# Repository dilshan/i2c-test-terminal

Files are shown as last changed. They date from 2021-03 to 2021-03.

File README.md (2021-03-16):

# I2C Master Mode Emulator

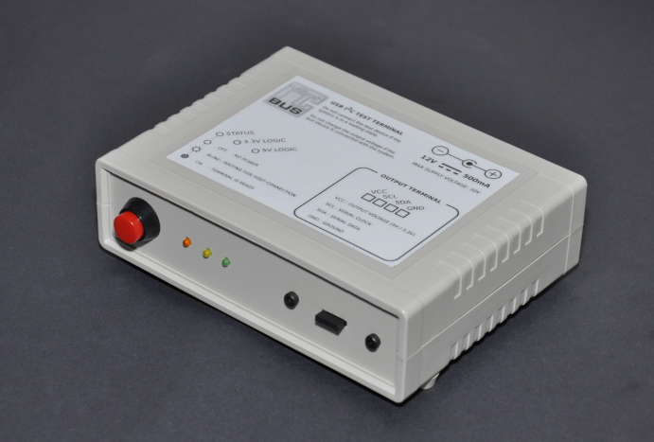
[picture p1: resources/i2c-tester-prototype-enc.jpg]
Prototype version of I2C master mode emulator


The I2C master mode emulator allows communication with I2C devices by sending or receiving data to/from the I2C bus. To issue the I2C commands, the emulator should connect to a PC over the USB port. After initializing the emulator, the PC and directly control the I2C slave chip/module.

This emulator is based on [ATmega16A](https://www.microchip.com/wwwproducts/en/ATmega16A) MCU. The USB communication channel is develop using the [V-USB](https://www.obdev.at/products/vusb/index.html) firmware.

To simplify the assembly, the PCB of this emulator is designed on a single-side board. The dimensions of the PCB are 96.77mm × 110.73mm. All the parts used in this project are through-hole-type, generally available components.

This emulator needs an external power supply, and the recommended supply voltage is between 12V - 15V.

The control software of the emulator is developed using libusb and tested only with *Linux* operating systems. The current firmware and control software support I2C emulation on 100kHz, 250kHz, and 400kHz clock rates.

Initially, we develop this emulator to work with 5V I2C devices, but later it has extended to work with 3.3V I2C devices. The 3.3V design is still under testing, and at the prototyping stage, we found a couple of issues in 3.3V mode.

In 3.3V mode, the required output level is available only if the emulator is in a "*ready*" state. In all the other states, it provides 5V output. **Therefore in 3.3V mode, necessary precautions need to be taken to protect the slave device from over-voltage damages.**

This project is an open-source hardware project. All the content of this project are distributed under the terms of the following license:

-   Hardware License: [CC BY 4.0](https://creativecommons.org/licenses/by/4.0/)
-   Software and firmware License: [MIT](https://github.com/dilshan/i2c-test-terminal/blob/main/LICENSE)
-   [Documentation](https://github.com/dilshan/i2c-test-terminal/wiki) License: [CC BY 4.0](https://creativecommons.org/licenses/by/4.0/)

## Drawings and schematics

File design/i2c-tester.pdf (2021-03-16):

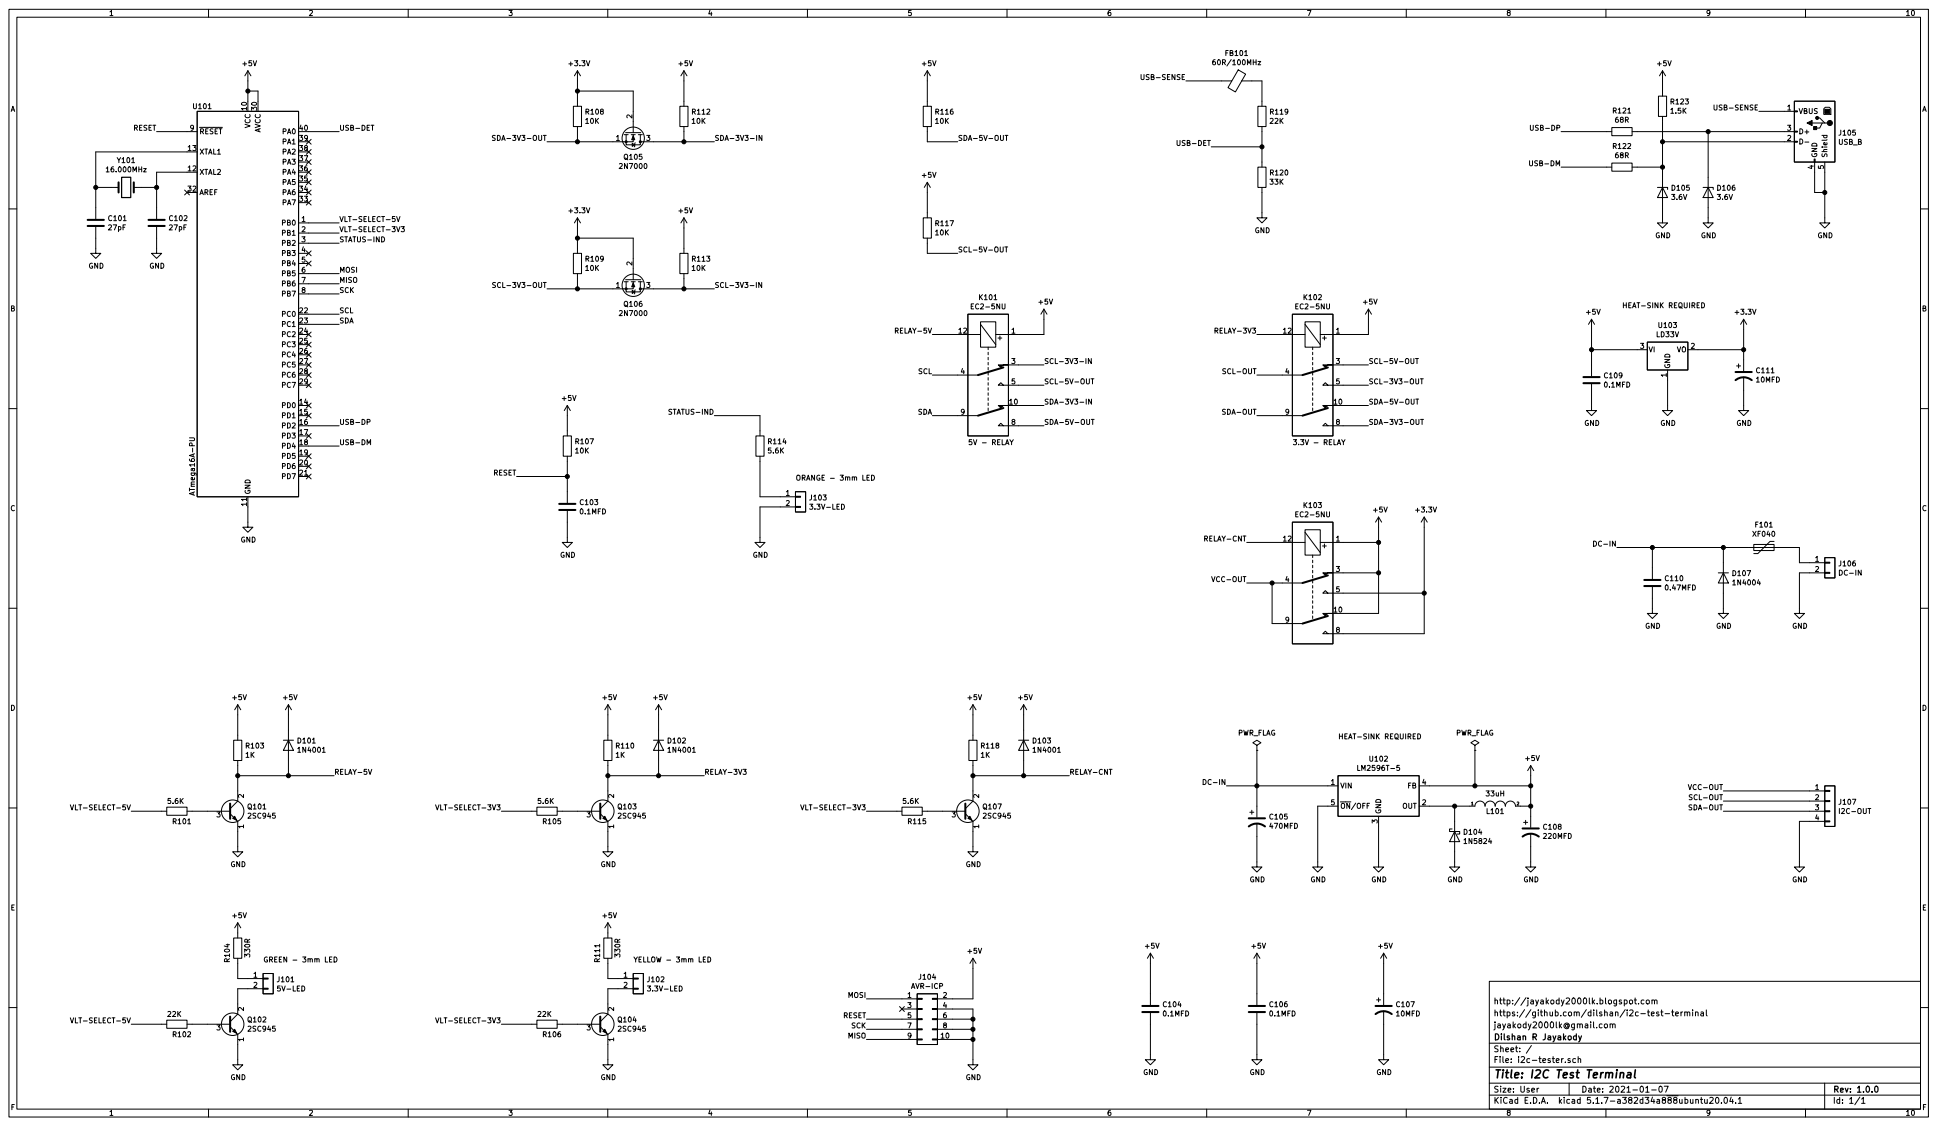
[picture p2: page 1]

SDA-3V3-OUT SCL-3V3-OUT USB-SENSEUSB-DET

2N7000 SDA USB-DET
SDA-3V3-OUT VLT-SELECT-5V

VCC-OUT SCL-3V3-IN

USB-DP USB-DM

http://jayakody2000lk.blogspot.com
https://github.com/dilshan/i2c-test-terminal
jayakody2000lk@gmail.com
Id: 1/1 Title: I2C Test Terminal File: i2c-tester.sch Sheet: / Dilshan R Jayakody

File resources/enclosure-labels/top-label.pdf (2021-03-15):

12V | 500mA

+ _

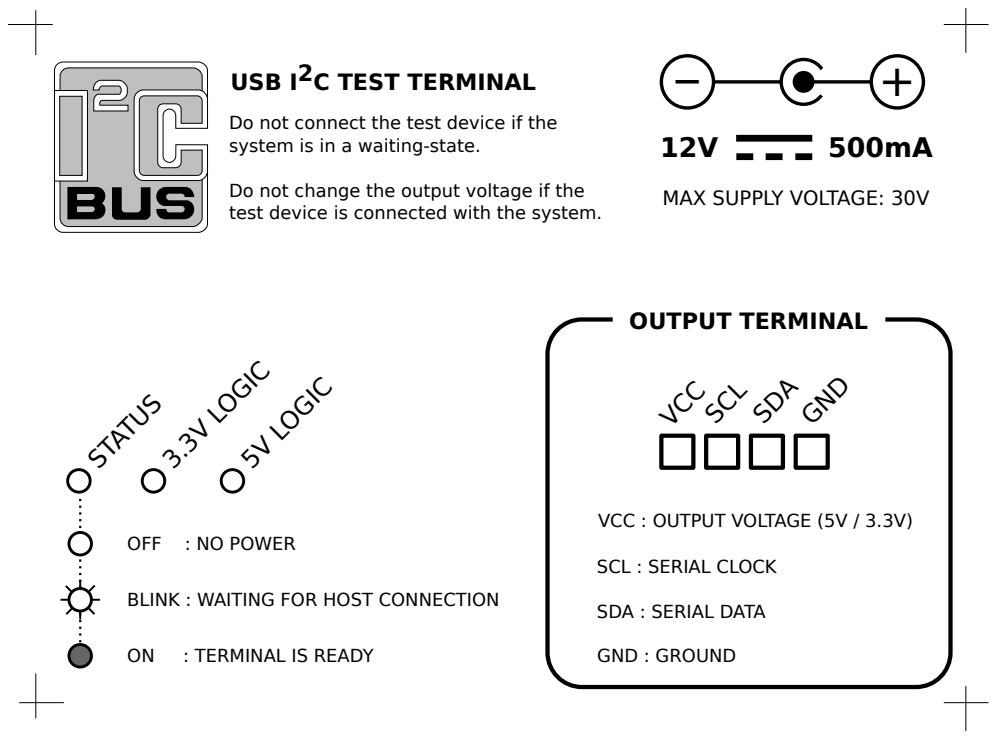
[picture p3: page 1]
STATUS; 3.3V LOGIC; : TERMINAL IS READY; 5V LOGIC; GND : GROUND; VCC; SCL; SDA; GND; OUTPUT TERMINAL

USB I2C TEST TERMINAL

Do not connect the test device if the
system is in a waiting-state.

Do not change the output voltage if the
test device is connected with the system.

MAX SUPPLY VOLTAGE: 30V

VCC : OUTPUT VOLTAGE (5V / 3.3V)

OFF : NO POWER

SCL : SERIAL CLOCK

BLINK : WAITING FOR HOST CONNECTION

SDA : SERIAL DATA

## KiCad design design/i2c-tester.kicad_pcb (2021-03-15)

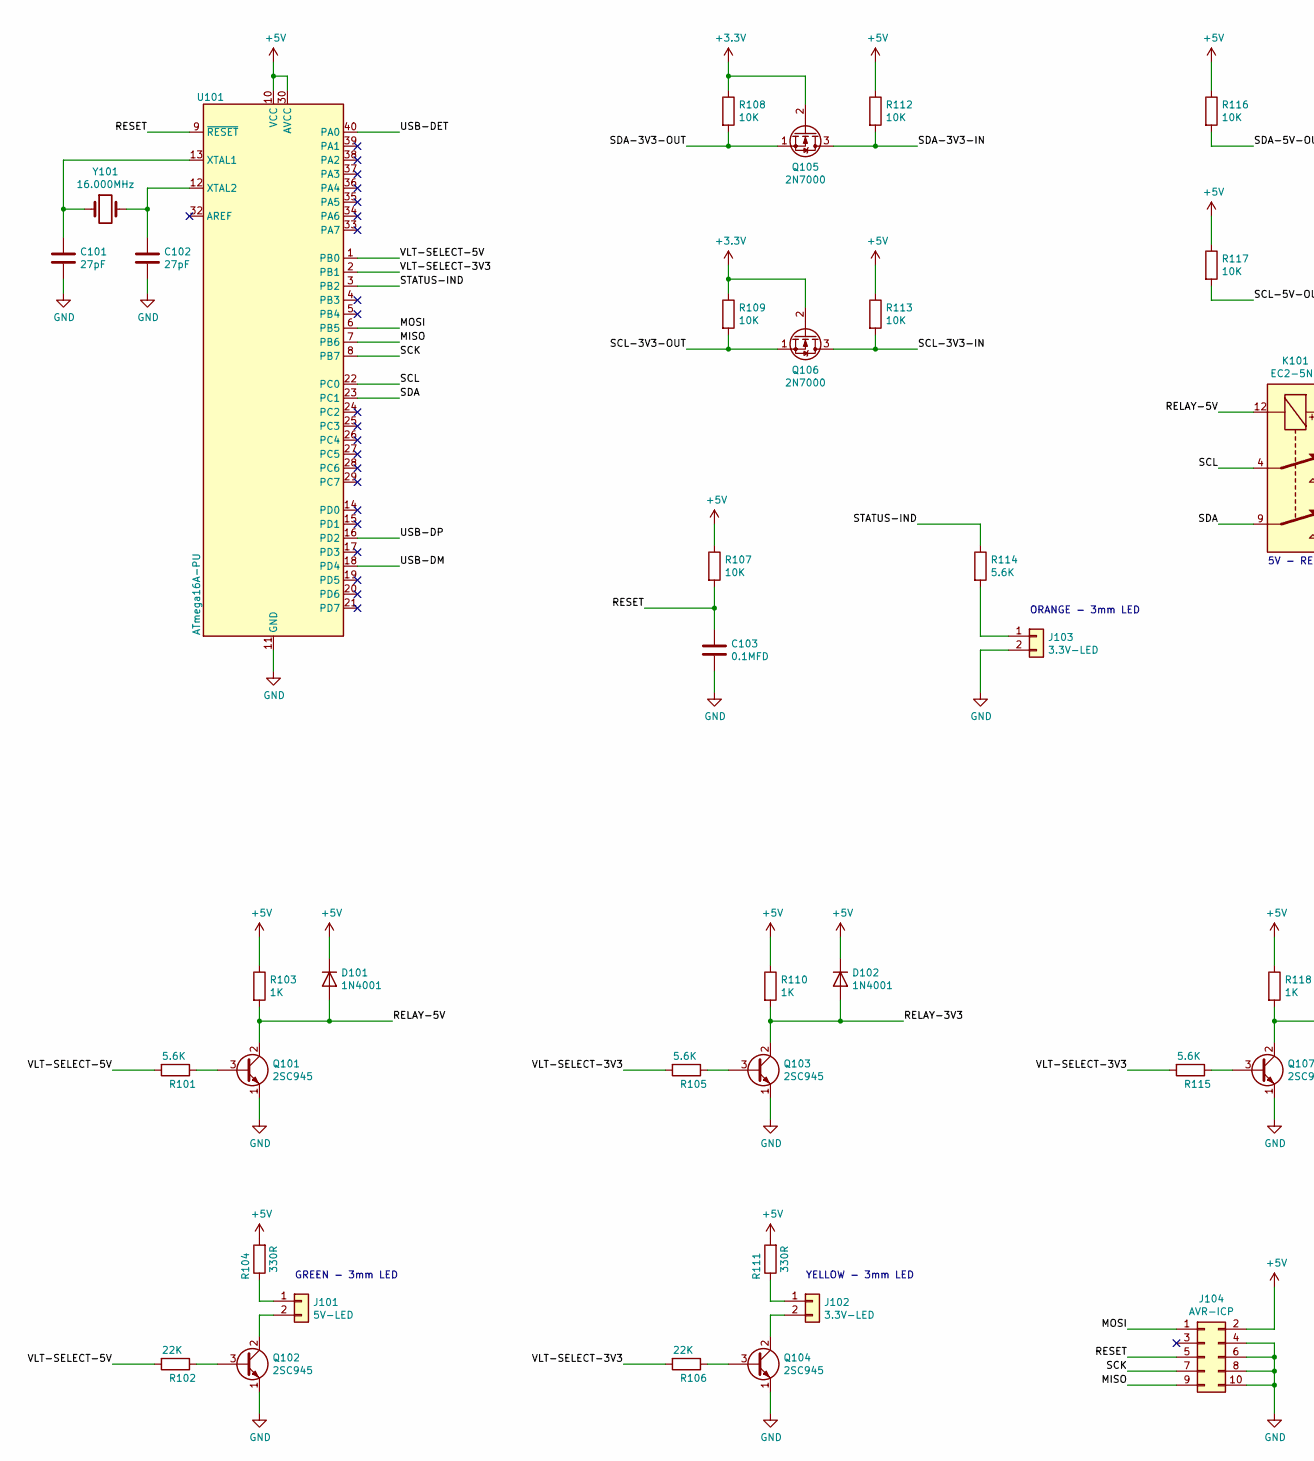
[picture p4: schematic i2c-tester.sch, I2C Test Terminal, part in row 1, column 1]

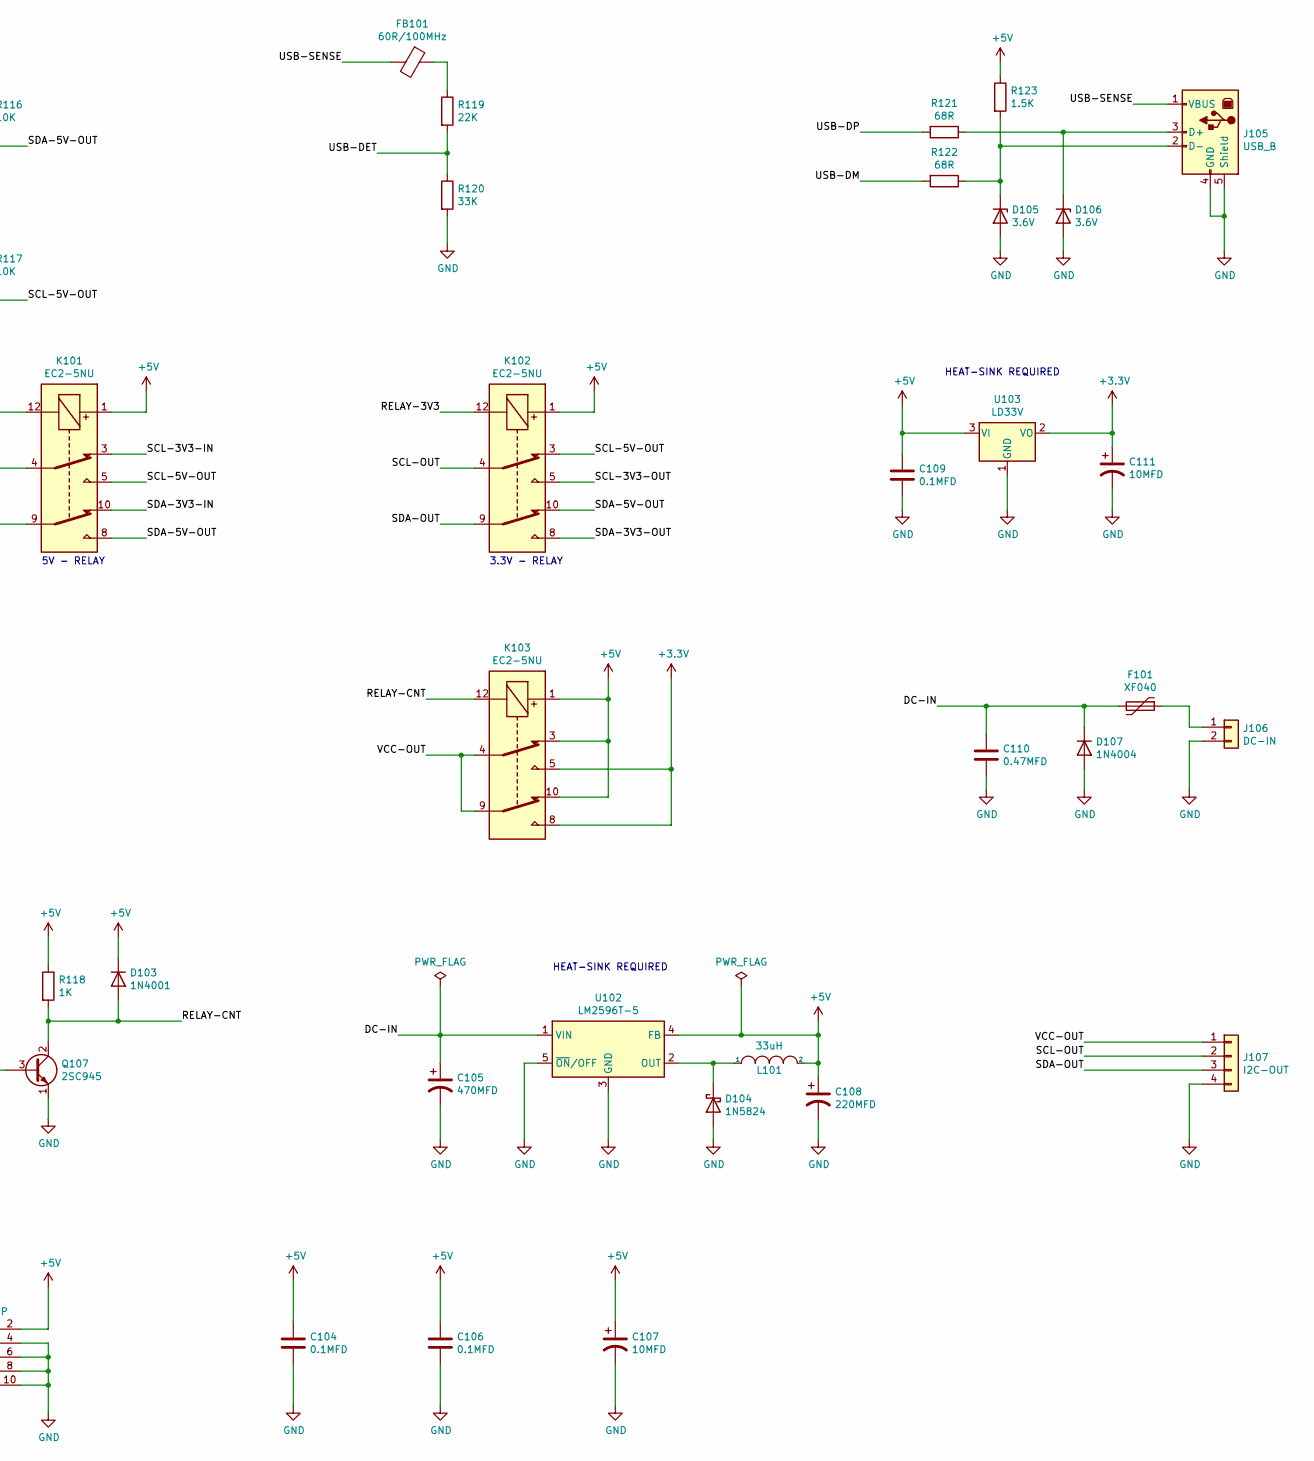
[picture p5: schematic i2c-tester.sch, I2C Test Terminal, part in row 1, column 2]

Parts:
C101, C102: 27pF; C_Disc_D5.0mm_W2.5mm_P2.50mm
C103, C104, C106, C109: 0.1MFD; C_Disc_D12.5mm_W5.0mm_P10.00mm
C105: 470MFD; CP_Radial_D8.0mm_P3.50mm
C107, C111: 10MFD; CP_Radial_D5.0mm_P2.00mm
C108: 220MFD; CP_Radial_D6.3mm_P2.50mm
C110: 0.47MFD; C_Rect_L16.5mm_W7.0mm_P15.00mm_MKT
D101, D102, D103: 1N4001; D_DO-41_SOD81_P10.16mm_Horizontal
D104: 1N5824; D_DO-41_SOD81_P10.16mm_Horizontal
D105, D106: 3.6V; D_DO-35_SOD27_P7.62mm_Horizontal
D107: 1N4004; D_DO-41_SOD81_P10.16mm_Horizontal
F101: XF040; Fuse_Bourns_MF-RG300
FB101: 60R/100MHz; L_Axial_L6.6mm_D2.7mm_P10.16mm_Horizontal_Vishay_IM-2
J101: 5V-LED; PinHeader_1x02_P2.54mm_Vertical
J102, J103: 3.3V-LED; PinHeader_1x02_P2.54mm_Vertical
J104: AVR-ICP; PinHeader_2x05_P2.54mm_Vertical
J105: USB_B; USB_B_Lumberg_2411_02_Horizontal
J106: DC-IN; PhoenixContact_MCV_1,5_2-G-5.08_1x02_P5.08mm_Vertical
J107: I2C-OUT; PinHeader_1x04_P2.54mm_Vertical
K101, K102, K103: EC2-5NU; Relay_DPDT_Kemet_EC2
L101: 33uH; L_Toroid_Vertical_L14.0mm_W5.6mm_P5.30mm_Bourns_5700
Q101, Q102, Q103, Q104, Q107: 2SC945; TO-92_HandSolder
Q105, Q106: 2N7000; TO-92_HandSolder
R101, R105, R114, R115: 5.6K; R_Axial_DIN0309_L9.0mm_D3.2mm_P15.24mm_Horizontal
R102, R106, R119: 22K; R_Axial_DIN0309_L9.0mm_D3.2mm_P15.24mm_Horizontal
R103, R110, R118: 1K; R_Axial_DIN0309_L9.0mm_D3.2mm_P15.24mm_Horizontal
R104, R111: 330R; R_Axial_DIN0309_L9.0mm_D3.2mm_P15.24mm_Horizontal
R107, R108, R109, R112, R113, R116, R117: 10K; R_Axial_DIN0309_L9.0mm_D3.2mm_P15.24mm_Horizontal
R120: 33K; R_Axial_DIN0309_L9.0mm_D3.2mm_P15.24mm_Horizontal
R121, R122: 68R; R_Axial_DIN0309_L9.0mm_D3.2mm_P15.24mm_Horizontal
R123: 1.5K; R_Axial_DIN0309_L9.0mm_D3.2mm_P15.24mm_Horizontal
U101: ATmega16A-PU; DIP-40_W15.24mm_Socket_LongPads
U102: LM2596T-5; TO-220-5_P3.4x3.7mm_StaggerOdd_Lead3.8mm_Vertical
U103: LD33V; TO-220-3_Vertical
Y101: 16.000MHz; Crystal_HC49-U_Vertical

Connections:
+3V3: C111.1, K103.5, K103.8, Q105.2 (G), Q106.2 (G), R108.1, R109.1, U103.2 (VO)
+5V: C104.1, C106.1, C107.1, C108.1, C109.1, D101.1 (K), D102.1 (K), D103.1 (K), J104.2, K101.1, K102.1, K103.1, K103.3, K103.10, L101.2, R103.1, R104.2, R107.1, R110.1, R111.2, R112.1, R113.1, R116.1, R117.1, R118.1, R123.1, U101.10 (VCC), U101.30 (AVCC), U102.4 (FB), U103.3 (VI)
/DC-IN: C105.1, C110.1, D107.1 (K), F101.2, U102.1 (VIN)
/MISO: J104.9, U101.7 (PB6)
/MOSI: J104.1, U101.6 (PB5)
/RELAY-3V3: D102.2 (A), K102.12, Q103.2 (C), R110.2
/RELAY-5V: D101.2 (A), K101.12, Q101.2 (C), R103.2
/RELAY-CNT: D103.2 (A), K103.12, Q107.2 (C), R118.2
/RESET: C103.1, J104.5, R107.2, U101.9 (~RESET)
/SCK: J104.7, U101.8 (PB7)
/SCL: K101.4, U101.22 (PC0)
/SCL-3V3-IN: K101.3, Q106.3 (D), R113.2
/SCL-3V3-OUT: K102.5, Q106.1 (S), R109.2
/SCL-5V-OUT: K101.5, K102.3, R117.2
/SCL-OUT: J107.2, K102.4
/SDA: K101.9, U101.23 (PC1)
/SDA-3V3-IN: K101.10, Q105.3 (D), R112.2
/SDA-3V3-OUT: K102.8, Q105.1 (S), R108.2
/SDA-5V-OUT: K101.8, K102.10, R116.2
/SDA-OUT: J107.3, K102.9
/STATUS-IND: R114.1, U101.3 (PB2)
/USB-DET: R119.2, R120.1, U101.40 (PA0)
/USB-DM: R122.2, U101.18 (PD4)
/USB-DP: R121.2, U101.16 (PD2)
/USB-SENSE: FB101.2, J105.1 (VBUS)
/VCC-OUT: J107.1, K103.4, K103.9
/VLT-SELECT-3V3: R105.2, R106.2, R115.2, U101.2 (PB1)
/VLT-SELECT-5V: R101.2, R102.2, U101.1 (PB0)
GND: C101.2, C102.2, C103.2, C104.2, C105.2, C106.2, C107.2, C108.2, C109.2, C110.2, C111.2, D104.2 (A), D105.2 (A), D106.2 (A), D107.2 (A), J103.2, J104.4, J104.6, J104.8, J104.10, J105.4 (GND), J105.5 (Shield), J106.2, J107.4, Q101.1 (E), Q102.1 (E), Q103.1 (E), Q104.1 (E), Q107.1 (E), R120.2, U101.11 (GND), U101.31 (GND), U102.3 (GND), U102.5 (~ON~/OFF), U103.1 (GND)
unnamed: C101.1, U101.13 (XTAL1), Y101.1
unnamed: C102.1, U101.12 (XTAL2), Y101.2
unnamed: D104.1 (K), L101.1, U102.2 (OUT)
unnamed: D105.1 (K), J105.2 (D-), R122.1, R123.2
unnamed: D106.1 (K), J105.3 (D+), R121.1
unnamed: F101.1, J106.1
unnamed: FB101.1, R119.1
unnamed: J101.1, R104.1
unnamed: J101.2, Q102.2 (C)
unnamed: J102.1, R111.1
unnamed: J102.2, Q104.2 (C)
unnamed: J103.1, R114.2
unnamed: Q101.3 (B), R101.1
unnamed: Q102.3 (B), R102.1
unnamed: Q103.3 (B), R105.1
unnamed: Q104.3 (B), R106.1
unnamed: Q107.3 (B), R115.1

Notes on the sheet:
5V - RELAY
3.3V - RELAY
GREEN - 3mm LED
YELLOW - 3mm LED
ORANGE - 3mm LED
HEAT-SINK REQUIRED

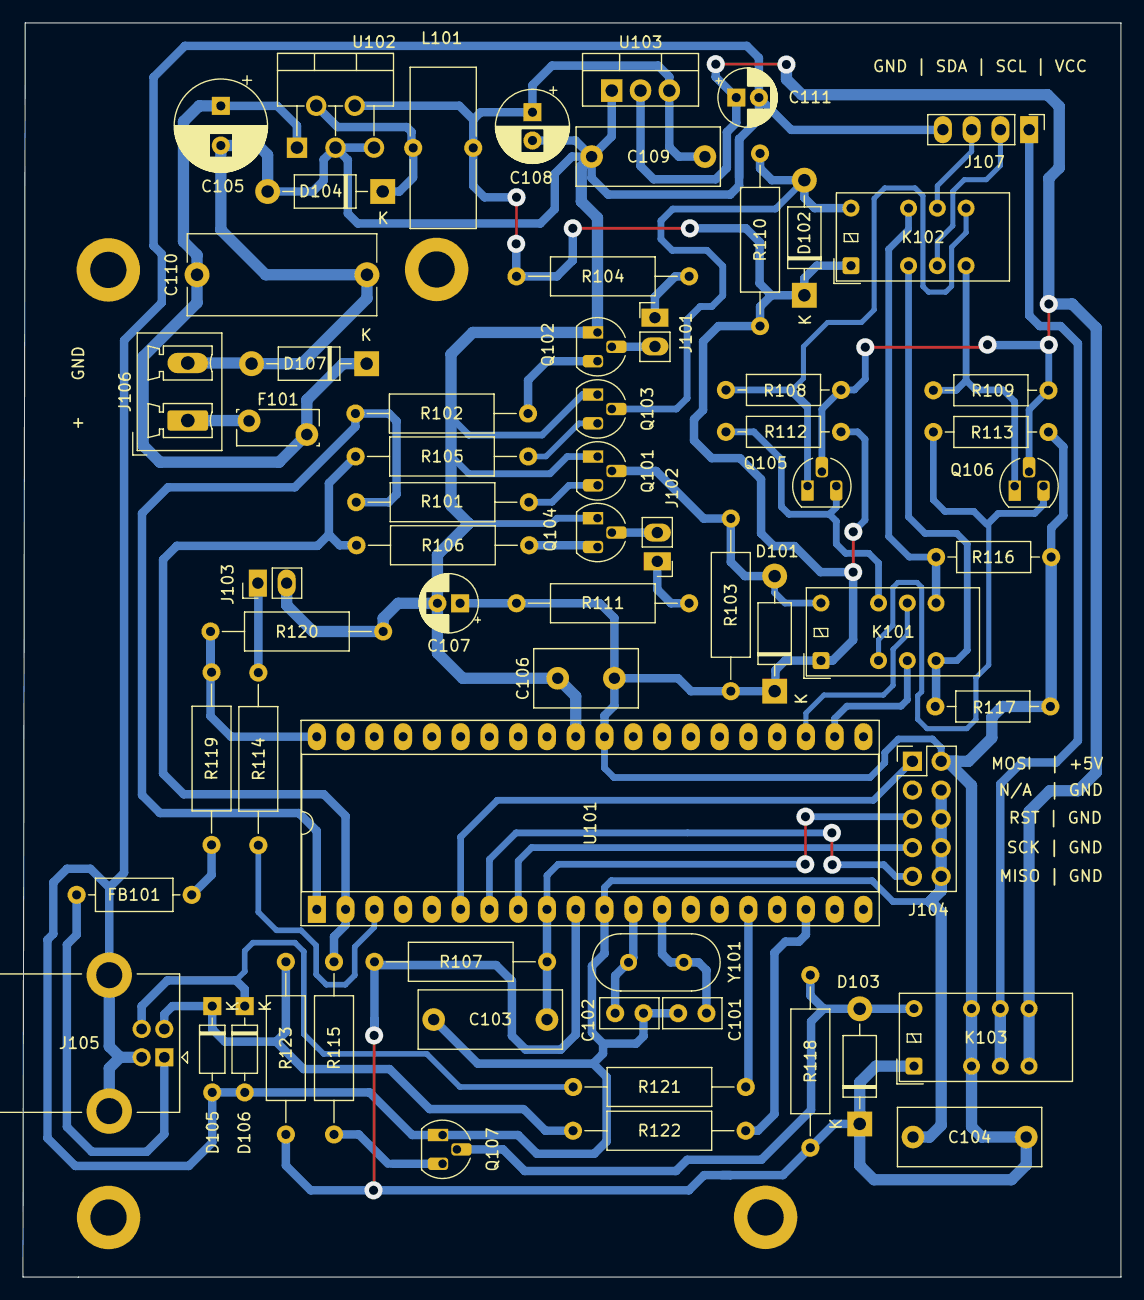
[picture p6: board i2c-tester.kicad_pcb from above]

Board: 2 copper layers, 96.9 x 110.7 mm, 65 parts (0 on the bottom side), 46 nets.

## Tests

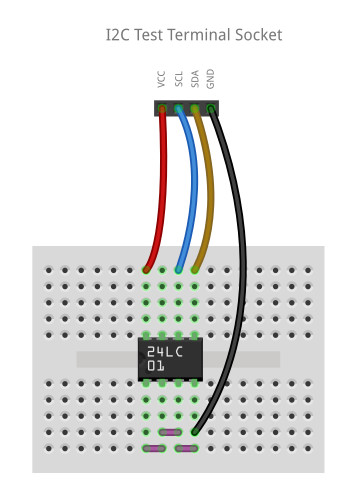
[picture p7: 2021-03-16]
resources/i2c-tester-sample-connection.jpg

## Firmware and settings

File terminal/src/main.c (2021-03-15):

//----------------------------------------------------------------------------------
// I2C Test Terminal - Core Functions and Main Entry Point.
//
// Copyright (c) 2021 Dilshan R Jayakody [jayakody2000lk@gmail.com].
//
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
#include "main.h"
#include "strdef.h"
#include "termutil.h"
#include "cmdproc.h"

#include <linux/types.h>
#include <linux/input.h>
#include <linux/hidraw.h>

#include <sys/ioctl.h>
#include <sys/types.h>
#include <sys/stat.h>
#include <fcntl.h>
#include <unistd.h>
#include <pthread.h>
#include <termios.h>

#include <stdlib.h>
#include <stdio.h>
#include <string.h>
#include <time.h> 
#include <ctype.h>

int main()
{
    struct udev *udev;
    struct UsbComData comIntf;
    char *hidDevPath;
    unsigned char *cmdData;
    EXEC_STATUS status;
    pthread_t devThread;
    int termHandler;
    unsigned char currentVoltage, refreshVoltage;
        
    // Try to find the I2C terminal device on udev. If available get the device path.
    udev = udev_new();
    status = getTerminalDevicePath(udev, &hidDevPath);
    udev_unref(udev);

    if(status == EXEC_FAIL)
    {
        // Unable to find the device or udev error.
        printErrorMsg(DEV_NOT_AVAILABLE);
        return 1;
    }    

    // Open USB device for communication.
    termHandler = open(hidDevPath, (O_RDWR | O_NONBLOCK));
    if(termHandler < 0)
    {
        printErrorMsg(DEV_NOT_OPEN);
        return 1;
    }

    // Display intro message(s).
    printf(MSG_INTRO_NAME);
    printf(MSG_INTRO_HELP);

    // Get current output voltage from the device.
    currentVoltage = 0;
    refreshVoltage = 0;
    if(getCurrentOutputVoltage(termHandler, &currentVoltage) == EXEC_SUCCESS)
    {
        // Current output voltage received from the device.
        printf(MSG_OUTPUT_VOLTAGE, (currentVoltage == I2C_OUTPUT_5V) ? "5.0" : "3.3");
    }
    else
    {
        // Output voltage probe request is fail.
        printErrorMsg(DEV_COM_OUTPUT_VOLTAGE_FAIL);
        return 1;
    }
    
    // Get commands from the user.
    while(getCommand(&cmdData) == CMD_STATUS_OK)
    {
        if(cmdData != NULL)
        {            
            // Confirmation is required to change the I2C output voltage.
            if(cmdData[1] == USB_CMD_SET_VOLTAGE)
            {                
                // Check specified voltage is same as the current voltage level.
                if(cmdData[2] != currentVoltage)
                {
                    // Specified voltage level is different from current voltage level.
                    if(isContinue(PROMPT_VOLTAGE_CHANGE) == EXEC_FAIL)
                    {
                        // Voltage change is canceled by the user.
                        free(cmdData);
                        cmdData = NULL;

                        // No change required, skip USB data submission.
                        continue;
                    }
                }
                else
                {
                    // Specified voltage level is equal to the current voltage level.
                    printWarningMsg(CMD_VOLTAGE_SAME);

                    // Release command buffer.
                    free(cmdData);
                    cmdData = NULL;

                    // No change required, skip USB data submission.
                    continue;
                }

                // After the command execute get the voltage level from the device.
                refreshVoltage = 1;
            }

            // Execute command available in the data buffer.
            comIntf.comData = cmdData;
            comIntf.deviceHandler = termHandler;
            pthread_create(&devThread, NULL, sendDataToDevice, (void*)&comIntf);

            // Wait to finish the USB command.
            pthread_join(devThread, NULL);

            // Release command buffer.
            free(cmdData);
            cmdData = NULL;

            if(refreshVoltage)
            {
                // Need to refresh the voltage level of the system. (associated with voltage-change and reset commands.)
                refreshVoltage = 0;

                if(getCurrentOutputVoltage(termHandler, &currentVoltage) == EXEC_SUCCESS)
                {
                    // Current output voltage received from the device.
                    printf(MSG_OUTPUT_VOLTAGE, (currentVoltage == I2C_OUTPUT_5V) ? "5.0" : "3.3");
                }
                else
                {
                    // Output voltage probe request is fail.
                    printErrorMsg(DEV_COM_OUTPUT_VOLTAGE_FAIL);
                    return 1;
                }
            }
        }
    }

    // Release command buffer.
    if(cmdData != NULL)
    {
        free(cmdData);
        cmdData = NULL;
    }

    // Close USB device handler and terminate the application.
    close(termHandler);
    return 0;
}

EXEC_STATUS isContinue(const unsigned char *msg)
{
    char getConfirmation;
    static struct termios conConfigOld, conConfigNew;

    // Print specified message on the terminal.
    printf("%s (Y/N) ? ", msg);

    // Cancel character printing on the termina.
    tcgetattr(0, &conConfigOld);
    conConfigNew = conConfigOld;
    conConfigNew.c_lflag &= ~ICANON;
    conConfigNew.c_lflag &= ~ECHO;
    tcsetattr(0, TCSANOW, &conConfigNew);    

    // Loop until user specify the correct input.
    do
    {
        getConfirmation = getchar();
    } 
    while (!((getConfirmation == 'y') || (getConfirmation == 'Y') || (getConfirmation == 'n') || (getConfirmation == 'N')));

    // Restore terminal settings (to print characters on screen).
    tcsetattr(0, TCSANOW, &conConfigOld);

    // Print user selection and move to next line.
    printf("%c\n", toupper(getConfirmation));

    // Return success on "YES", otherwise return fail.
    return ((getConfirmation == 'y') || (getConfirmation == 'Y')) ? EXEC_SUCCESS : EXEC_FAIL;
}

EXEC_STATUS getCurrentOutputVoltage(int deviceHandler, unsigned char *voltage)
{
    unsigned char *reqData, *respData;
    struct timespec req, rem;
    int status;
    unsigned char result = EXEC_FAIL;

    // Create request buffer and send it to the device.
    reqData = createUSBBuffer(USB_CMD_GET_VOLTAGE, 0);
    respData = NULL;

    status = ioctl(deviceHandler, HIDIOCSFEATURE(USB_SET_COMMAND_BUFFER_SIZE), reqData);
    if(status >= 0)
    {
        // IOCTL is successful, creating data buffer to capture the output from the device.
        respData = (unsigned char*)calloc(USB_GET_DATA_BUFFER_SIZE, 1);
        while(ioctl(deviceHandler, HIDIOCGFEATURE(USB_GET_DATA_BUFFER_SIZE), respData) >= 0)
        {
            if((respData[1] == SYS_SIGNATURE) && (respData[2] == reqData[1]) && (respData[3] != RET_PENDING))
            {
                // Device respond with data / status.
                *voltage = respData[4];
                result = EXEC_SUCCESS;
                break;
            }
            
            // Wait thread for 250ms to get the next feature report.
            req.tv_sec = 0;
            req.tv_nsec = 250 * 1000000; 
            nanosleep(&req , &rem);

            memset(respData, 0, USB_GET_DATA_BUFFER_SIZE);
        }
    }
    
    // Release all allocated data buffers.
    free(reqData);
    reqData = NULL;

    if(respData != NULL)
    {
        free(respData);
        respData = NULL;
    }

    return result;
}

void *sendDataToDevice(void *dataPtr)
{
    struct UsbComData *comData = (struct UsbComData *)dataPtr;
    struct timespec req, rem;
    int status;
    unsigned char readBuffer[USB_GET_DATA_BUFFER_SIZE];

    // Send specified USB data buffer to the device.
    status = ioctl(comData->deviceHandler, HIDIOCSFEATURE(USB_SET_COMMAND_BUFFER_SIZE), comData->comData);
    if(status < 0)
    {
        // Communication failure has occur while setting up the feature report.
        printErrorMsg(DEV_COM_FAIL);
    }
    else
    {
        // IOCTL is successful, waiting for response from the device.
        memset(readBuffer, 0, USB_GET_DATA_BUFFER_SIZE);
        while(ioctl(comData->deviceHandler, HIDIOCGFEATURE(USB_GET_DATA_BUFFER_SIZE), readBuffer) >= 0)
        {            
            if((readBuffer[1] == SYS_SIGNATURE) && (readBuffer[2] == comData->comData[1]) && (readBuffer[3] != RET_PENDING))
            {
                // Device respond with data / status.
                break;
            }

            // Wait thread for 250ms to get the next feature report.
            req.tv_sec = 0;
            req.tv_nsec = 250 * 1000000; 
            nanosleep(&req , &rem);

            memset(readBuffer, 0, USB_GET_DATA_BUFFER_SIZE);
        }

        // print received data and status on terminal.
        printDeviceStatusMsg(readBuffer[3]);

        // On READ command show received data.            
        if(readBuffer[2] == USB_CMD_I2C_READ)
        {
            printData(readBuffer[4]);
        }
    }    
}

EXEC_STATUS getTerminalDevicePath(struct udev *udev, char **hidRawPath)
{
    EXEC_STATUS returnVal;
    struct udev_enumerate *devEnum;
    struct udev_list_entry *devices, *devEntry;
    struct udev_device *rawDev, *hidDev, *usbDev;
    const char *sysfsPath, *devPath, *devVID, *devPID;
    int parseStatus;
    unsigned short vid, pid;    

    *hidRawPath = NULL;
    returnVal = EXEC_FAIL;

    // Perform device scan on HID-RAW device class.
    devEnum = udev_enumerate_new(udev);
    udev_enumerate_add_match_subsystem(devEnum, "hidraw");
    udev_enumerate_scan_devices(devEnum);

    // Get the list of HID devices attached to the system.
    devices = udev_enumerate_get_list_entry(devEnum);

    // Check for the VID and PID to identify the I2C terminal device entry.
    udev_list_entry_foreach(devEntry, devices)
    {
        devVID = NULL;
        devPID = NULL;
        vid = 0;
        pid = 0;
        
        // Get devices HID RAW udev node.
        sysfsPath = udev_list_entry_get_name(devEntry);
        rawDev = udev_device_new_from_syspath(udev, sysfsPath);

        // Get devices HID udev node.
        devPath = udev_device_get_devnode(rawDev);
        hidDev = udev_device_get_parent_with_subsystem_devtype(rawDev, "hid", NULL);

        if(hidDev)
        {
            // Get USB device class to extract VID and PID values.
            usbDev = udev_device_get_parent_with_subsystem_devtype(rawDev, "usb", "usb_device");
            if(usbDev)
            {
                devVID = udev_device_get_sysattr_value(usbDev, "idVendor");
                devPID = udev_device_get_sysattr_value(usbDev, "idProduct");

                // Get vendor ID of the selected device.
                if((devVID) && (strlen(devVID) > 0))
                {
                    vid = strtol(devVID, NULL, 16);
                }

                // Get product ID of the selected device.
                if((devPID) && (strlen(devPID) > 0))
                {
                    pid = strtol(devPID, NULL, 16);
                }

                // Check for valid VID and PID.
                if((vid == I2C_TERMINAL_DEV_VID) && (pid == I2C_TERMINAL_DEV_PID))
                {
                    // Copy HID-RAW device path into specified variable.
                    *hidRawPath = (char*) malloc(strlen(devPath) + 1);
                    strcpy(*hidRawPath, devPath);

                    returnVal = EXEC_SUCCESS;
                }

                free((char*) devVID);
                free((char*) devPID);

                udev_device_unref(usbDev);
            }
        }

        free((char*) devPath);
    }

    // Cleanup allocated data structures.
    udev_enumerate_unref(devEnum);

    return returnVal;
}

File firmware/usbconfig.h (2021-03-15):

/* Name: usbconfig.h
 * Project: V-USB, virtual USB port for Atmel's(r) AVR(r) microcontrollers
 * Author: Christian Starkjohann
 * Creation Date: 2005-04-01
 * Tabsize: 4
 * Copyright: (c) 2005 by OBJECTIVE DEVELOPMENT Software GmbH
 * License: GNU GPL v2 (see License.txt), GNU GPL v3 or proprietary (CommercialLicense.txt)
 */

#ifndef __usbconfig_h_included__
#define __usbconfig_h_included__

/*
General Description:
This file is an example configuration (with inline documentation) for the USB
driver. It configures V-USB for USB D+ connected to Port D bit 2 (which is
also hardware interrupt 0 on many devices) and USB D- to Port D bit 4. You may
wire the lines to any other port, as long as D+ is also wired to INT0 (or any
other hardware interrupt, as long as it is the highest level interrupt, see
section at the end of this file).
*/

/* ---------------------------- Hardware Config ---------------------------- */

#define USB_CFG_IOPORTNAME      D
/* This is the port where the USB bus is connected. When you configure it to
 * "B", the registers PORTB, PINB and DDRB will be used.
 */
#define USB_CFG_DMINUS_BIT      4
/* This is the bit number in USB_CFG_IOPORT where the USB D- line is connected.
 * This may be any bit in the port.
 */
#define USB_CFG_DPLUS_BIT       2
/* This is the bit number in USB_CFG_IOPORT where the USB D+ line is connected.
 * This may be any bit in the port. Please note that D+ must also be connected
 * to interrupt pin INT0! [You can also use other interrupts, see section
 * "Optional MCU Description" below, or you can connect D- to the interrupt, as
 * it is required if you use the USB_COUNT_SOF feature. If you use D- for the
 * interrupt, the USB interrupt will also be triggered at Start-Of-Frame
 * markers every millisecond.]
 */
#define USB_CFG_CLOCK_KHZ       (F_CPU/1000)
/* Clock rate of the AVR in kHz. Legal values are 12000, 12800, 15000, 16000,
 * 16500, 18000 and 20000. The 12.8 MHz and 16.5 MHz versions of the code
 * require no crystal, they tolerate +/- 1% deviation from the nominal
 * frequency. All other rates require a precision of 2000 ppm and thus a
 * crystal!
 * Since F_CPU should be defined to your actual clock rate anyway, you should
 * not need to modify this setting.
 */
#define USB_CFG_CHECK_CRC       0
/* Define this to 1 if you want that the driver checks integrity of incoming
 * data packets (CRC checks). CRC checks cost quite a bit of code size and are
 * currently only available for 18 MHz crystal clock. You must choose
 * USB_CFG_CLOCK_KHZ = 18000 if you enable this option.
 */

/* ----------------------- Optional Hardware Config ------------------------ */

/* #define USB_CFG_PULLUP_IOPORTNAME   D */
/* If you connect the 1.5k pullup resistor from D- to a port pin instead of
 * V+, you can connect and disconnect the device from firmware by calling
 * the macros usbDeviceConnect() and usbDeviceDisconnect() (see usbdrv.h).
 * This constant defines the port on which the pullup resistor is connected.
 */
/* #define USB_CFG_PULLUP_BIT          4 */
/* This constant defines the bit number in USB_CFG_PULLUP_IOPORT (defined
 * above) where the 1.5k pullup resistor is connected. See description
 * above for details.
 */

/* --------------------------- Functional Range ---------------------------- */
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

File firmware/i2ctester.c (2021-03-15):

//----------------------------------------------------------------------------------
// I2C Test Terminal Firmware - Core Functions and Main Entry Point.
//
// Copyright (c) 2021 Dilshan R Jayakody [jayakody2000lk@gmail.com].
//
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
#include <avr/io.h>
#include <avr/interrupt.h>
#include <util/delay.h>
#include <avr/wdt.h>

#include "usbdrv.h"

#include "i2ctester.h"
#include "i2cdrv.h"

PROGMEM const char usbHidReportDescriptor[22] = {    /* USB report descriptor */
    0x06, 0x00, 0xff,              //   USAGE_PAGE (Generic Desktop)
    0x09, 0x01,                    //   USAGE (Vendor Usage 1)
    0xa1, 0x01,                    //   COLLECTION (Application)
    0x15, 0x00,                    //   LOGICAL_MINIMUM (0)
    0x26, 0xff, 0x00,              //   LOGICAL_MAXIMUM (255)
    0x75, 0x08,                    //   REPORT_SIZE (8)
    0x95, 0x80,                    //   REPORT_COUNT (128)
    0x09, 0x00,                    //   USAGE (Undefined)
    0xb2, 0x02, 0x01,              //   FEATURE (Data,Var,Abs,Buf)
    0xc0                           //   END_COLLECTION
};

int main()
{
    unsigned char connectDelay = 0;
    unsigned char outputVoltage = I2C_OUTPUT_3V3;
    
    // Initialize system registers and global variables.
    wdt_disable();
    initSystem();
    clearRequestBuffer();

    // Check device is connected to the USB host.
    if((PINA & 0x01) == 0x00)
    {
        // Device is not connected to the USB host, waiting for connection.
        do
        {
            // Blink Device Status LED and check USB sense pin.
            if(PORTB & 0x04)
            {
                PORTB &= 0xFB;
            }
            else
            {
                PORTB |= 0x04;
            }
            
            _delay_ms(250);
        } 
        while ((PINA & 0x01) == 0x00);
    }

    // USB device is connected to the host.
    PORTB |= 0x04;

    // Initialize V-USB driver.
    usbInit();
    usbDeviceDisconnect(); 

    while(--connectDelay)
    {
        _delay_ms(1);
    }

    usbDeviceConnect();
    sei();

    // Switch on lowest possible output voltage.
    setOutputVoltage(I2C_OUTPUT_3V3, &outputVoltage);
    
    // Main service loop.
    while(1)
    {
        // Check USB connection status.
        if((PINA & 0x01) == 0x00)
        {
            // Connection with USB host is not available, reset the device.
            PORTB &= 0xFB;

            // Activate WDT to perform device reset. 
            cli();
            wdt_enable(WDTO_15MS);
            while(1);
        }
        
        // Process pending USB messages and clear request buffer.
        if((reqBuffer[0] == SYS_SIGNATURE) && (reqBuffer[1] != USB_CMD_NONE))
        {
            switch(reqBuffer[1])
            {
            case USB_CMD_I2C_INIT:
                // Initialize I2C session.
                i2cInit(reqBuffer[2]);   // DATA0 - I2C communication speed (ref: i2cdrv.h)
                lastCommandStatus = RET_SUCCESS;
                break;
            case USB_CMD_I2C_START:
                // Send I2C start command.
                lastCommandStatus = i2cStart(usbPoll);
                break;
            case USB_CMD_I2C_STOP:
                // Send I2C stop command.
                i2cStop();
                lastCommandStatus = RET_SUCCESS;           
                break;
            case USB_CMD_I2C_WRITE_ADDR:
                // Send I2C write address command.
                lastCommandStatus = i2cWriteAddr(usbPoll, reqBuffer[2]);  // DATA0 - slave device address and read/write flag.
                break;
            case USB_CMD_I2C_WRITE:
                // Send I2C write command.
                lastCommandStatus = i2cWrite(usbPoll, reqBuffer[2]);  // DATA0 - data to write into slave device.
                break;
            case USB_CMD_I2C_READ:
                // Send I2C read command.
                lastCommandStatus = i2cRead(usbPoll, reqBuffer[2], &lastCommandData); // DATA0 - ACK status for read command.            
                break;
            case USB_CMD_SET_VOLTAGE:
                // Set I2C output voltage.                
                lastCommandStatus = setOutputVoltage(reqBuffer[2], &outputVoltage); // DATA0 - Voltage level, 0x01 - 5V; 0x02 - 3.3V;
                break;
            case USB_CMD_GET_VOLTAGE:
                // Get current I2C output voltage.
                lastCommandData = outputVoltage;
                lastCommandStatus = RET_SUCCESS;
                break;
            case USB_CMD_RESET:
                // Reset I2C slave device and I2C terminal registers.
                lastCommandStatus = resetI2CSlave(outputVoltage);
                break;            
            default:
                // Unknown command ID.
                lastCommandStatus = RET_UNKNOWN;
            }

            // Clear request buffer.
            clearRequestBuffer();
        }
        
        // Process USB messages received from the host.
        usbPoll();
    }

    return 0;
}

void initSystem()
{   
    // PORTB.0 [OUT] - 5V Control Terminal.
    // PORTB.1 [OUT] - 3.3V Control Terminal.
    // PORTB.2 [OUT] - Device Status LED.
    DDRB = 0x07;
    PORTB = I2C_OUTPUT_3V3;

    // Shutdown ADC and set PORTA.0 as USB sense pin.
    ADMUX = 0x00;
    ADCSRA = 0x00;
    ACSR = 0x80;

    DDRA = 0x00;
    PORTA = 0x00;
    
    // Initialize global variables.
    lastCommandStatus = RET_SUCCESS;
    lastCommandData = 0x00;
    lastCommand = USB_CMD_NONE;
}

void clearRequestBuffer()
{
    reqBuffer[0] = 0x00;
    reqBuffer[1] = USB_CMD_NONE;
    reqBuffer[2] = 0x00;
    reqBuffer[3] = 0x00;
}

unsigned char usbFunctionRead(unsigned char *data, unsigned char len)
{
    // Response data format:
    // SIGNATURE | COMMAND | STATUS | DATA | END SIGNATURE
    data[0] = SYS_SIGNATURE;
    data[1] = lastCommand;
    data[2] = lastCommandStatus;
    data[3] = lastCommandData;
    data[4] = SYS_END_SIGNATURE;

    return 4;
}

unsigned char usbFunctionWrite(unsigned char *data, unsigned char len)
{
    // Received command format: 
    // SIGNATURE | COMMAND | DATA BYTE | END SIGNATURE
    if((len > 4)  && (data[0] == SYS_SIGNATURE))
    {
        // Reset last command variables.
        lastCommandStatus = RET_PENDING;
        lastCommandData = 0x00;
        lastCommand = data[1];
        
        // Copy received data into request buffer.
        reqBuffer[0] = data[0];
        reqBuffer[1] = data[1];
        reqBuffer[2] = data[2];
        reqBuffer[3] = data[3];
    }
    
    // End of the data chunk.
    return 1;
}
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

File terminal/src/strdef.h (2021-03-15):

//----------------------------------------------------------------------------------
// I2C Test Terminal - Generic String Table.
//
// Copyright (c) 2021 Dilshan R Jayakody [jayakody2000lk@gmail.com].
//
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
#ifndef I2C_TERMINAL_STR_DEF
#define I2C_TERMINAL_STR_DEF

#define DEV_NOT_AVAILABLE   "I2C Terminal device is not connected to the system or not functioning properly."
#define DEV_NOT_OPEN        "Unable to open the USB device."

#define MSG_INTRO_NAME      "I2C Terminal - Copyright (c) 2021 Dilshan R Jayakody. (jayakody2000lk@gmail.com)\n"
#define MSG_INTRO_HELP      "Type \"\033[1m\033[37mhelp\033[0m\" to list down the available commands. Enter \"\033[1m\033[37mhelp [COMMAND]\033[0m\" to get the information about the specific command.\n"
#define MSG_OUTPUT_VOLTAGE  "Current I2C output voltage: \033[1m\033[37m%sV\033[0m\n"

#define CMD_MSG_UNKNOWN             "Unknown command."
#define CMD_MSG_PARAMETER_MISSING   "Required parameter(s) are missing."
#define CMD_MSG_OUTOF_RANGE         "Specified parameter is out of range."
#define CMD_MSG_SPEED_UNSUPPORT     "Unsupported I2C speed, only 100kHz, 250kHz and 400kHz are supported by the device."
#define CMD_PARAM_IGNORE            "Specified parameters are ignored by the command."
#define CMD_PARAM_READ_UNSUPPORTED  "Unsupported read flag, only \033[1m\033[37mack\033[0m, \033[1m\033[37mnack\033[0m, \033[1m\033[37m1\033[0m and \033[1m\033[37m0\033[0m are allowd as parameters."
#define CMD_PARAM_INVALID_VOLTAGE   "Invalid voltage level, only 3.3V or 5V output is available with the device."
#define CMD_VOLTAGE_SAME            "Current output voltage is same as the specified voltage."

#define PROMPT_VOLTAGE_CHANGE       "Selected voltage level is different from the current output voltage, continue the voltage change"

#define DEV_COM_FAIL                "Communication failure has occur while writing data to the device."
#define DEV_COM_TIMEOUT             "I2C timeout occur, slave device is not responding."
#define DEV_COM_UNKNOWN             "Unknown I2C error."
#define DEV_COM_OUTPUT_VOLTAGE_FAIL "Unable to get I2C output voltage from the device."

#define DEV_COM_START_TX        "A START condition has been transmitted."
#define DEV_COM_REPEAT_START    "A repeated START condition has been transmitted."
#define DEV_COM_SLAVE_W         "Slave address with WRITE flag has been transmitted, ACK has been received."
#define DEV_COM_SLAVE_W_NACK    "Slave address with WRITE flag has been transmitted, NOT ACK has been received."
#define DEV_COM_NOT_ACK         "Slave address with READ flag has been transmitted, ACK has been received."
#define DEV_COM_DATA_TX         "Data byte has been transmitted, ACK has been received."
#define DEV_COM_DATA_TX_NACK    "Data byte has been transmitted, NOT ACK has been received."
#define DEV_COM_ARIB_LOST       "Arbitration lost in Slave address (with WRITE flag) or data bytes."
#define DEV_COM_REPEATE_WAIT    "Slave address with READ flag has been transmitted, NOT ACK has been received"
#define DEV_COM_DATA_TX_ACK     "Data byte has been received, ACK has been returned."
#define DEV_COM_DATA_RX_NACK    "Data byte has been received, NOT ACK has been returned."

#endif /* I2C_TERMINAL_STR_DEF */

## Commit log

2021-03-15 Initial version of I2C Test Terminal source files and design files.
    [i2c-tester.kicad_pcb, i2c-tester.sch]
2021-03-15 Add enclosure label, design file and output file.
2021-03-16 Add image of the finished prototype and link it to readme.md file.
2021-03-16 Add PDF version of the current schematic.
2021-03-16 Fix minor lanugage issues in help / documentation.
    [strdoc.h]
2021-03-16 Add Fritzing diagram to show the test connection layout.
    [i2c-tester-sample-connection.fzz]
